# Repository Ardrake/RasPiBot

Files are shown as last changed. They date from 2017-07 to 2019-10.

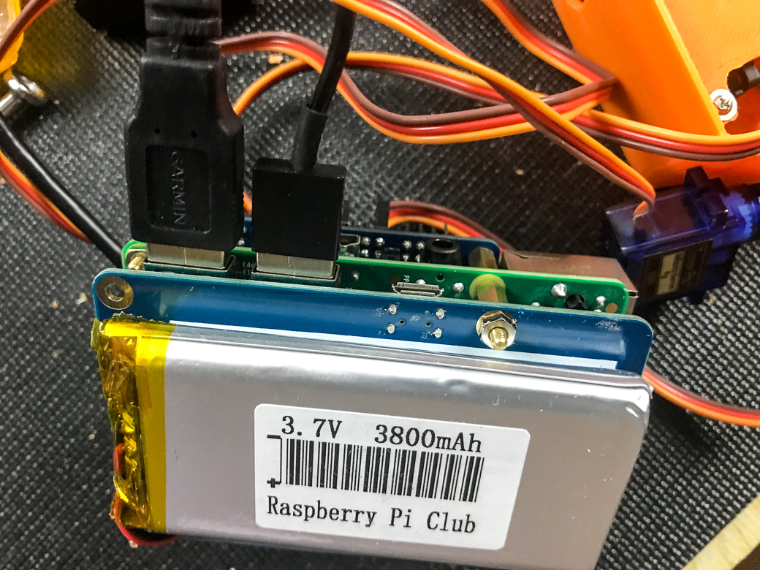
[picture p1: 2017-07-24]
test/Model MG996R/V3/IMG_0332.jpg

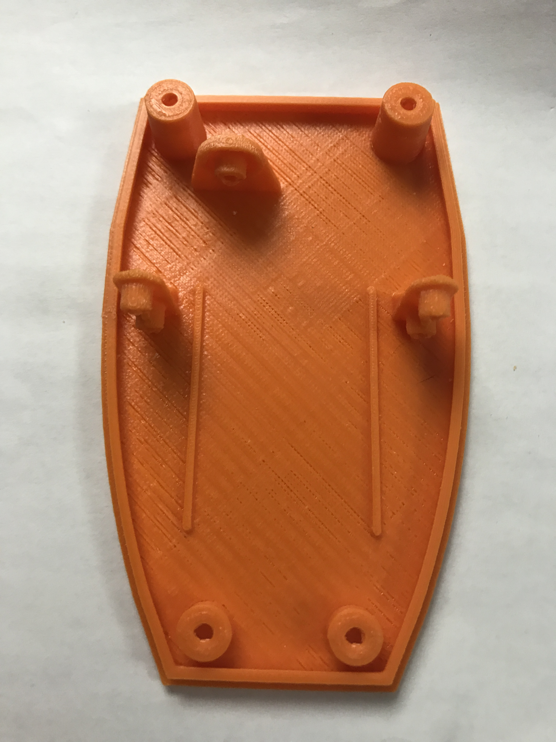
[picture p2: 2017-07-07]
test/Model MG996R/V3/IMG_0251.JPG

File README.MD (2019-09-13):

<p align="center">
    
</p>

<h4 align="center">A remix of the original <a href="http://www.robotshop.com/en/ez-robot-jd-humanoid-robot.html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" target="_blank">JD Robot</a>.</h4>

<p align="center">
<a href="">
    
  </a>
 
     <a href='https://ko-fi.com/A8722AIZ' target='_blank'>Buy Me a Coffee at ko-fi.com
    </a>
     <a href="https://opensource.org/licenses/MIT">
    
  </a>
  <a href="https://github.com/Ardrake">
    
  </a>
</p>

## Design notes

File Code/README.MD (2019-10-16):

## Section code / programation du projet

#### Requis

+ Python 3.6
+ wxPython
+ Adafruit 16-Channel PWM - Servo hat
+ Raspberry Pi B

------

+ Encours
  1. Écran de test pour servos

+ A faire
  1. Gestion et sauvegarde de la calibration des servos
  2. Gestion des mouvements en séquance (macro)
      - enregistrment
      - playback
  3. web cam support
  4. touch screen
  5. Conversion en web app ? / Flask / django

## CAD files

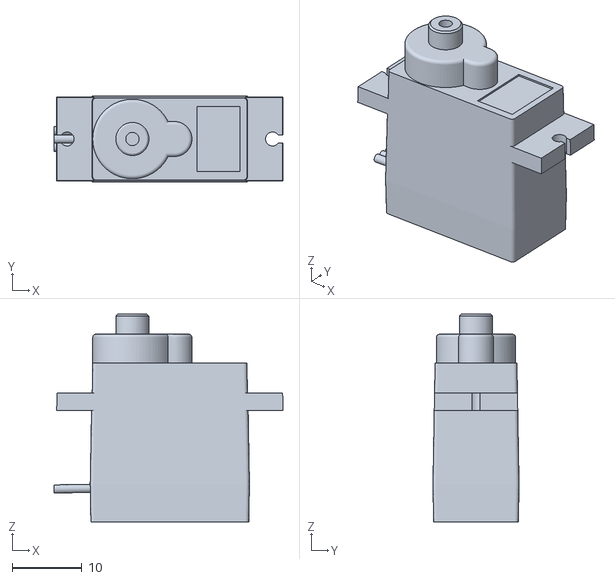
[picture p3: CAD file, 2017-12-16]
3D/Parts/2051_servo_tower-pro-sg90.pk2.stl
32.9 x 12.4 x 29.8

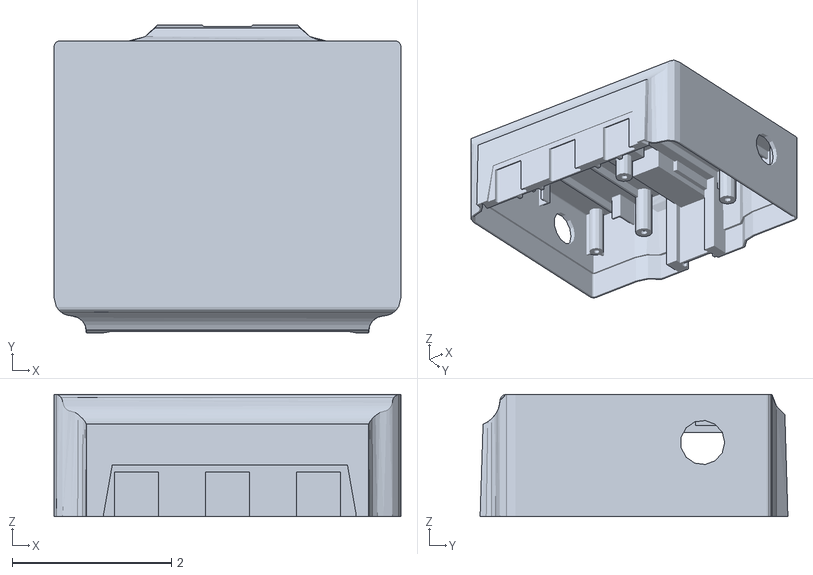
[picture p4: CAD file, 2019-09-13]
stl/P4_A-01_Cooke.stl
4.36 x 3.86 x 1.54

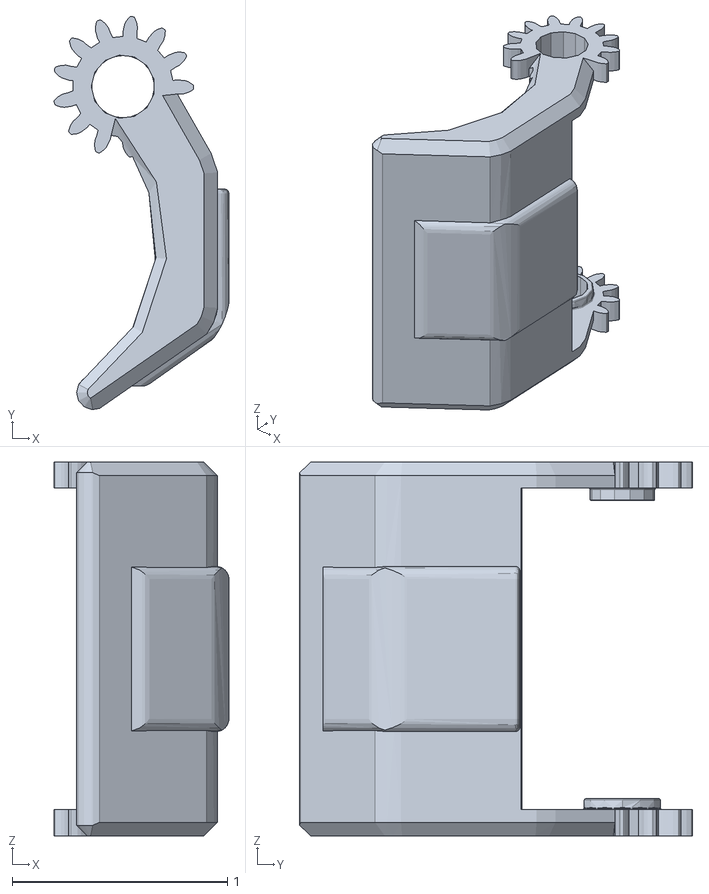
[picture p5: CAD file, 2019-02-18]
stl/P26_A-01_Cooke.stl
0.812 x 1.82 x 1.74

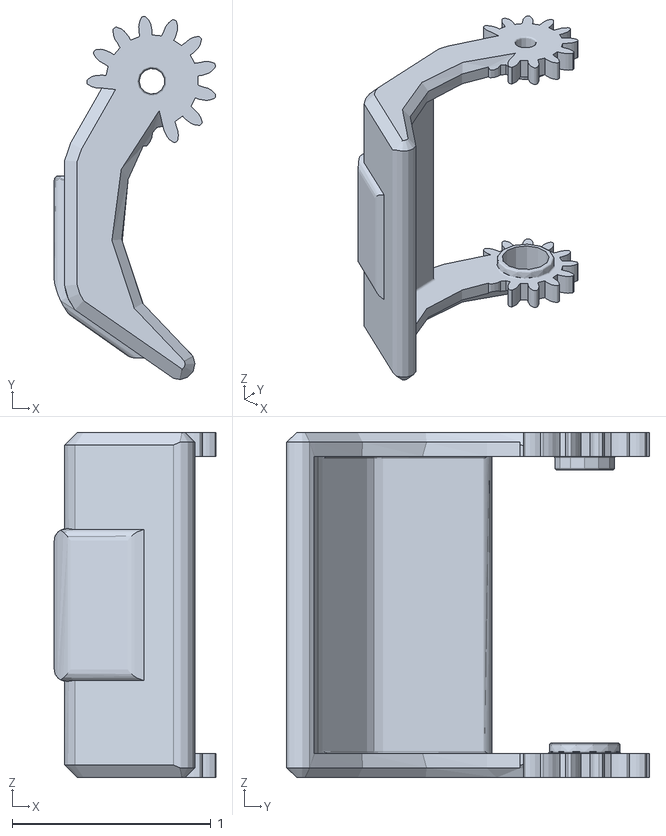
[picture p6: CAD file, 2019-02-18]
stl/P27_A-01_Cooke.stl
0.812 x 1.82 x 1.74

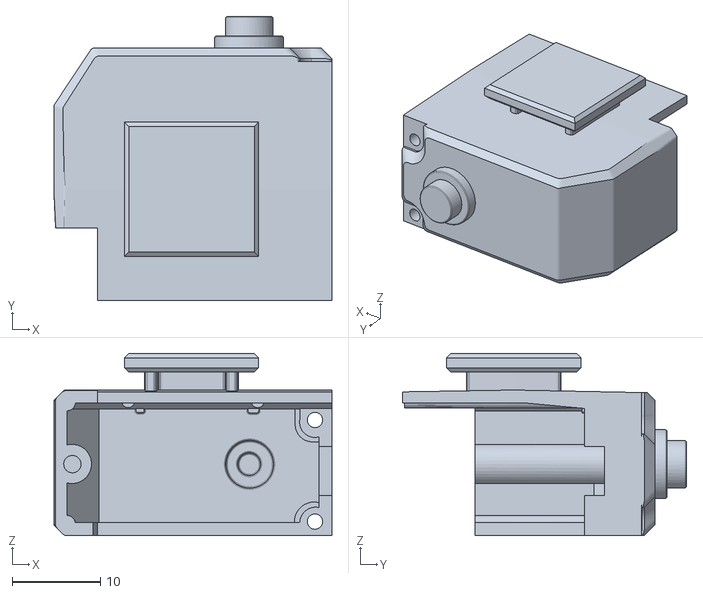
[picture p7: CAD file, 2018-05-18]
stl/P20_A-01_Cooke.stl
31.6 x 32.3 x 20.7

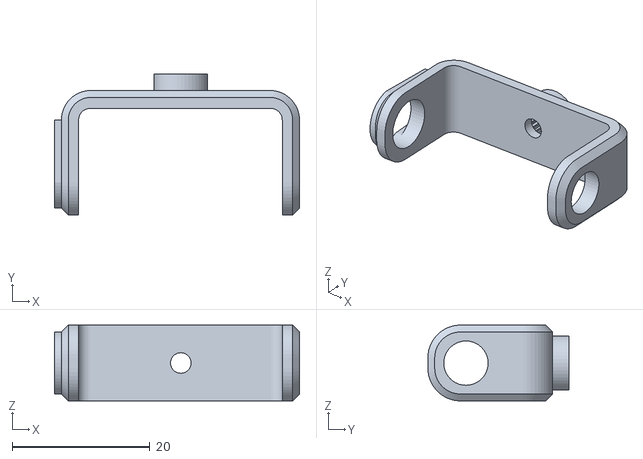
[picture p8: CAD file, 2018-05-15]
stl/P21_A-01_Cooke.stl
35.5 x 20.5 x 11.0

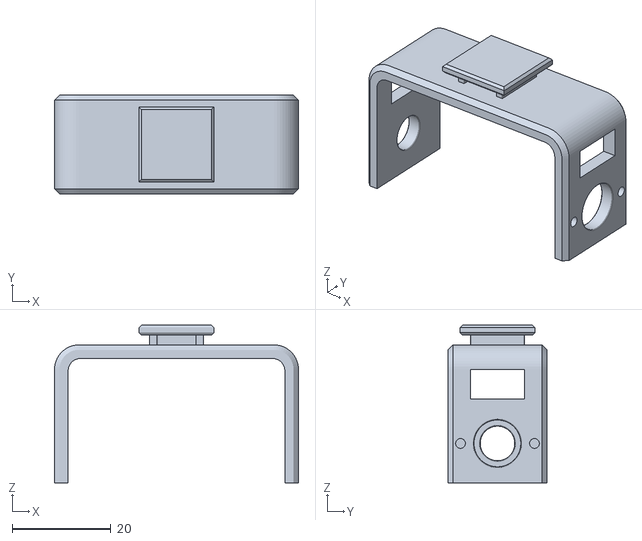
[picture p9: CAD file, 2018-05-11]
stl/P24_A-01_Cooke.stl
49.5 x 20.0 x 32.0

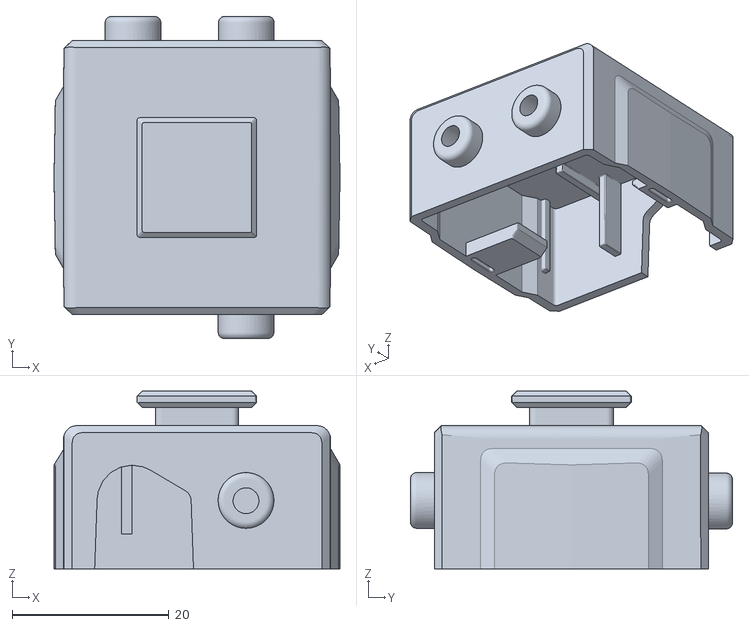
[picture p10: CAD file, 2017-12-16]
stl/P28_A-01_Cooke.stl
36.5 x 41.1 x 22.7

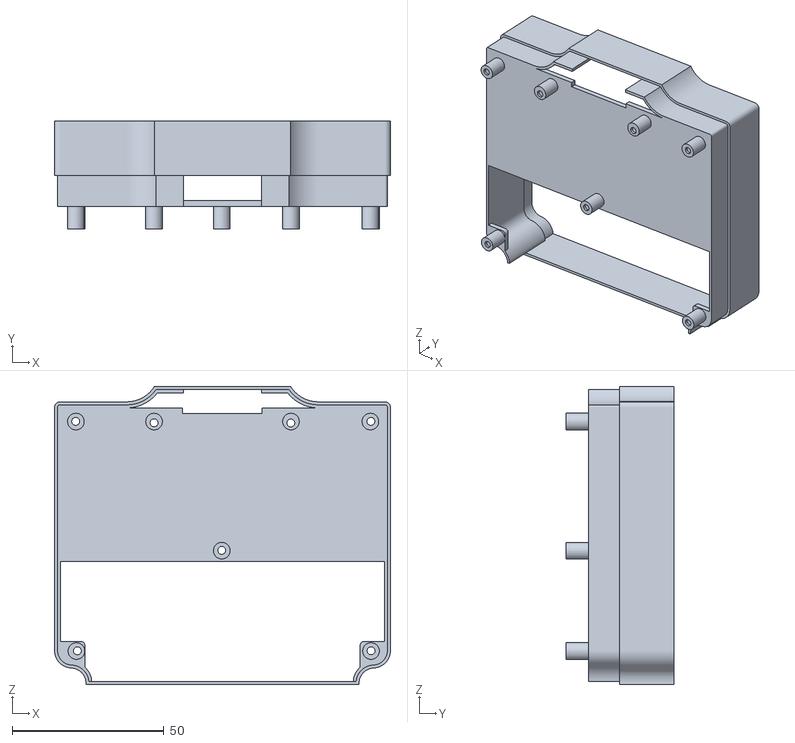
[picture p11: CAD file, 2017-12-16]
stl/Pi_BackPack.stl
110.6 x 35.5 x 98.1

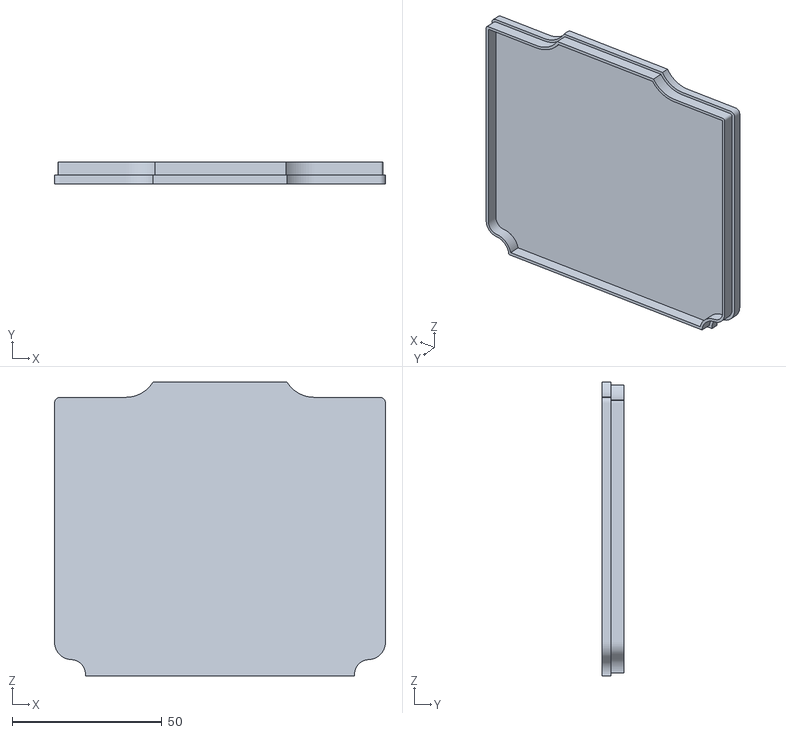
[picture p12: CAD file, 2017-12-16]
stl/BackCover.stl
110.6 x 7.34 x 98.1

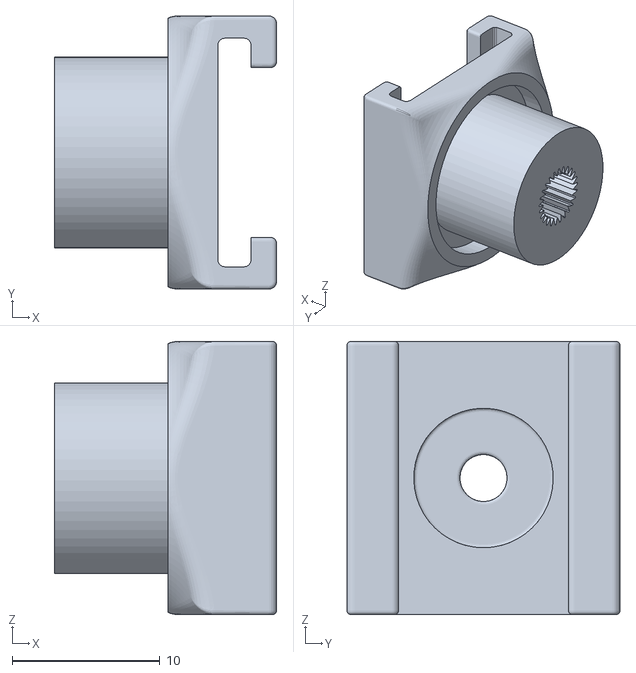
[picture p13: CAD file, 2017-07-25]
stl/P6_A-01_Cooke.stl
15.1 x 18.5 x 18.5

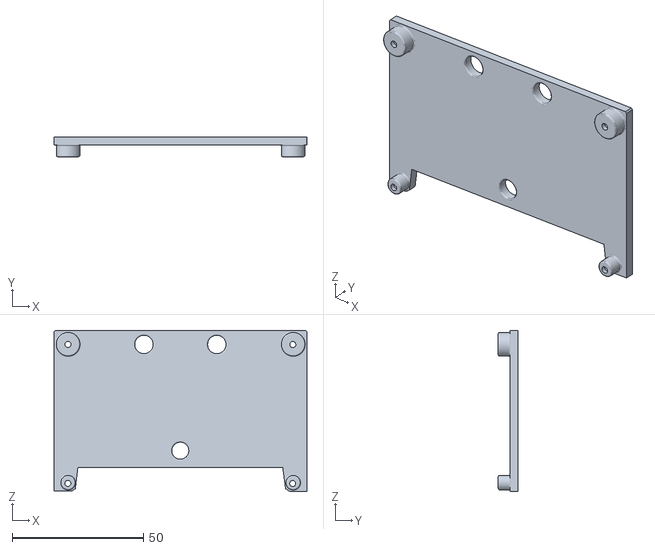
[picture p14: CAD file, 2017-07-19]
stl/P5_A-01_Cooke.stl
96.5 x 7.45 x 61.5

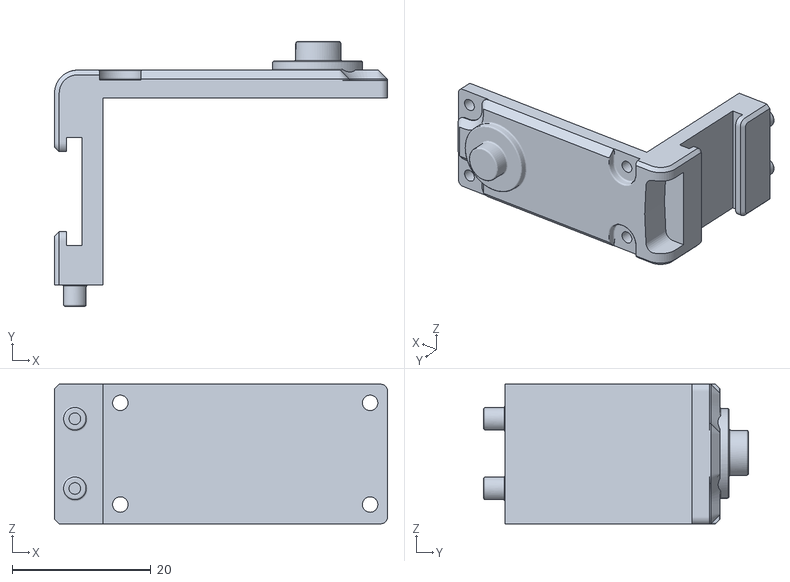
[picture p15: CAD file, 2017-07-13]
stl/P23_A-01_MG996R.stl
48.0 x 38.2 x 20.1

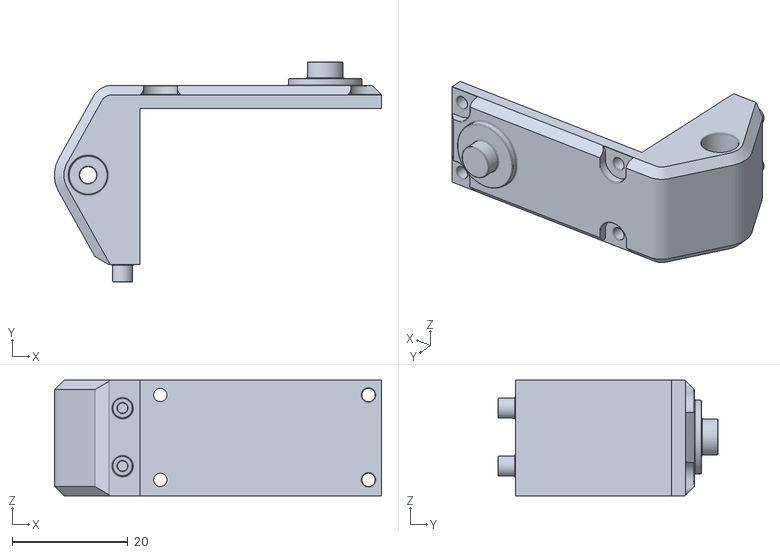
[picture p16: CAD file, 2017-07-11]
stl/P43_A-01_Cooke.stl
56.6 x 38.1 x 20.0

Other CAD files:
stl/P11_A-01_Cooke.stl
stl/P9_A-01_Cooke.stl
stl/P7_A-01_Cooke.stl
stl/P8_A-01_Cooke.stl
stl/P10_A-01_Cooke.stl
stl/P20_A-01.STL
stl/P21_A-01.STL
stl/P24_A-01_MG996R.stl
stl/P2_A-01.STL
stl/P3_A-01.STL
stl/P43_A-01.STL
stl/P5_A-01.STL

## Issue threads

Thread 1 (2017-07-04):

P-23

Ardrake, 2017-07-04:
P-23 needs to be ajusted for 996R servos

Ardrake, 2017-07-04:
Made modifications, will print and test part shortly

Ardrake, 2017-07-06:
Part modified to fit with MG996R motor, and test printed
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

Closed 2017-07-06.

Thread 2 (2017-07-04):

Raspberry PI - Touche screen chest plate

Ardrake, 2017-07-04:
Re-design chest part to include a Raspberry pi touch screen

Ardrake, 2017-07-19:
Augmenté la dimension en X, Y et z du chest pour fitté un Pi, ajusté les support pour les moteur MG996R, le back plate et back pack sont a suivre

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

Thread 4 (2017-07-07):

P-20 - screw tower

Ardrake, 2017-07-07:
Increase screw tower size, broke when screwed to bottom

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

Ardrake, 2017-07-08:
Piece modifié, besoin de re-imprimé pour validé modification

Ardrake, 2017-07-11:
Pièce imprimé et validé

Closed 2017-07-11.

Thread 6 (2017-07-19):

Battery / énergie portable

Ardrake, 2017-07-19:
quel sont les besoins et les options de batteries a utiliser pour le projet, faut t'il prévoir de l'espace dans le chest / backplate pour ceux si ??

SLAY666, 2017-07-19:
Je suis rendu là! Je connais vraiment pas ça! Le JD original a une belle
batterie qui fitte parfaitement par dessus les senseurs dans le Chest.
Cependant, je ne sais pas si elle peut gérer le PI et le hat.

Connais-tu ça un peu? Est-ce qu'une même batterie peut gérer 2 devices?

Le 19 juil. 2017 08:20, "André Cooke" <notifications@github.com> a écrit :

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

Ardrake, 2017-07-19:
Adafruit recommend, ceci pour le servo hat
4xAA Battery Holder - 6v with Alkaline cells.
4.8v with NiMH rechargeable cells, portable!
4.8 or 6v Rechargeable RC battery packs from a hobby store.

Ardrake, 2017-07-19:
ceci semble intéressant, 2 output de 5V, un pour le Pi et un pour le servo hat

https://www.adafruit.com/product/1566

Ardrake, 2017-07-19:
Option chinoise moins cher

http://www.gearbest.com/raspberry-pi/pp_603488.html#.WW9gP5KOxDY.link

SLAY666, 2017-07-19:
Oh que j'aime l'option chinoise, tu penses ça entre dans le Chest ou que ça
pourrait sarrimer avec le Chest d'une quelconque façon?

Le 19 juil. 2017 09:39, "André Cooke" <notifications@github.com> a écrit :

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

Ardrake, 2017-07-19:
http://amzn.to/2tf75Aa

connecteur USB a DC jack, mais un peut long, et après avoir regarder ça un peut splicé un cable usb direct

http://www.instructables.com/id/Provide-Power-With-an-Old-USB-Cord/

Ardrake, 2017-07-19:
http://amzn.to/2tGsP7l

Bon avec Amazon prime, je reçoit ça dans 2 jours, je vais branché en fds pour voir ça donne quoi! et si ca fonctionne, je vais modifié le chest pour lui trouvé un place, et avoir un accès pour le branché le fils du chargeur

SLAY666, 2017-07-19:
Wow, tu es en feu!!

Le 19 juillet 2017 à 10:56, André Cooke <notifications@github.com> a écrit :

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

Ardrake, 2017-07-21:
ca semble avoir pas mal d'allure la batterie, reste a voir comment inséré ca pour que ca prend le moins d'espace, ca fait 1 3/4 de de pouce d'épais quand on stack le tous

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

SLAY666, 2017-07-21:
Wow est cool ta batterie, je pensais qu'elle serait plus grosse. Sur JD,
ils placent la batterie sous les moteurs. Voir la photo, ça enlèverait de
l'épaisseur.

Es-tu en vacances pour 3 semaines?

Le 20 juil. 2017 22:59, "André Cooke" <notifications@github.com> a écrit :

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

Ardrake, 2017-07-21:
oui, asser grosse, les dimension hors tous sont de 8.5 cm X 5.5 cm x 2 cm, sous les moteurs ces un bonne idée, j'avais commencer a dégagé la zone et voir comment ca pourrait si logé.

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

le carré jaune étant l'espace requise pour la batterie, c'étais avant que je la reçoive par contre, la je vais peaufiné ça un peut.

Non malheureusement les vacances l'été c'est pas évident pour moi, c'est notre saison forte.

Dans mon domaine, j'ai une semaine seulement l'été, que je prend en septembre cette année, mais je me reprend cette hivers avec 4 semaine de congé au fêtes

Ardrake, 2017-08-18:
Battery testé et fonctionnelle, pour le build du robot, reste a validés les 3D et positionnement.

Je ferme cette issue

Closed 2017-08-18.

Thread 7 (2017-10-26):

Moteur SG90

Ardrake, 2017-10-26:
le moteur SG90 est plus petit que le moteur d'origine, modification des pièce requise

Ardrake, 2017-10-26:
J'ai modifé la piece P-28-A-01, elle doit etre imprimé et testé

SLAY666, 2017-10-26:
Merci je vais tester ça!!

2017-10-26 14:57 GMT-04:00 André Cooke <notifications@github.com>:

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

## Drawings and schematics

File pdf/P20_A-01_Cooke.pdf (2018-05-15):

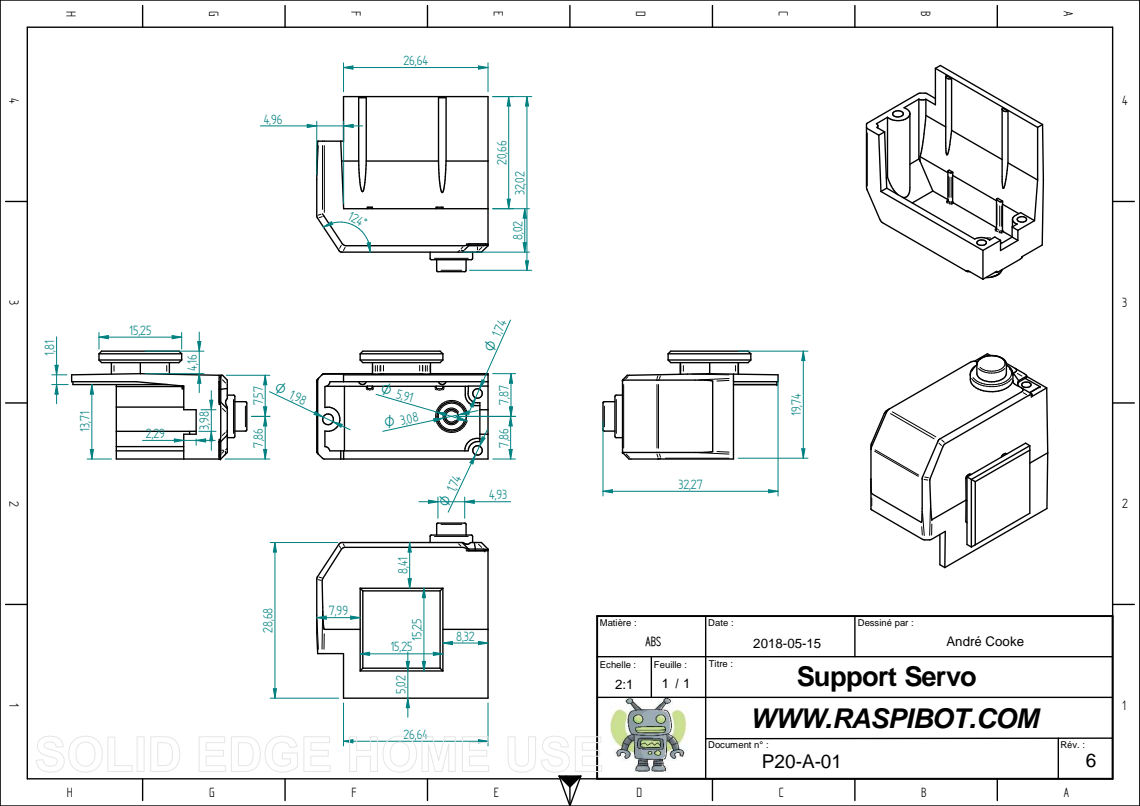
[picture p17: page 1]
HGFEDCB

Matière : ABS | Date : 2018-05-15 | Dessiné par : André Cooke

Echelle : 2:1 | Feuille : 1 1/ | Titre : Support Servo

WWW.RASPIBOT.COM

Document n° : P20-A-01 | Rév. : 6

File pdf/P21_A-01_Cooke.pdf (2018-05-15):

4

29,53

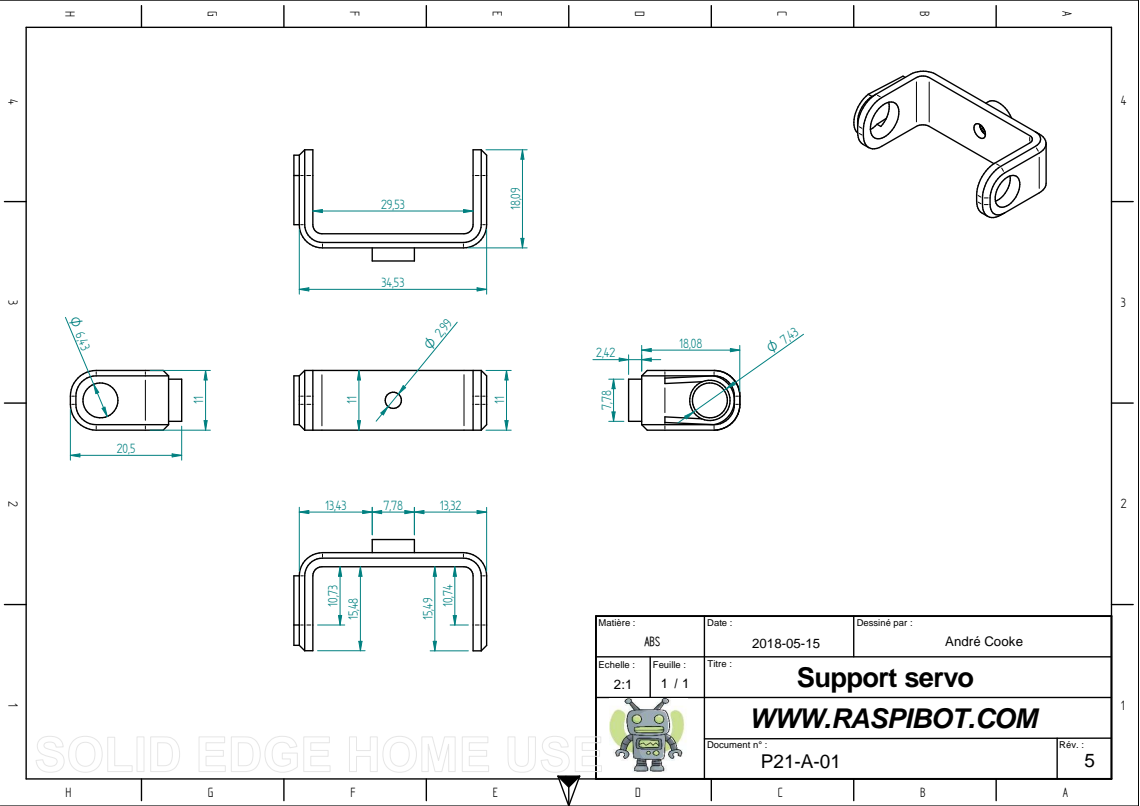
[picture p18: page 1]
HGFEDCB

Matière : ABS | Date : 2018-05-15 | Dessiné par : André Cooke

Echelle : 2:1 | Feuille : 1 1/ | Titre : Support servo

WWW.RASPIBOT.COM

Document n° : P21-A-01 | Rév. : 5

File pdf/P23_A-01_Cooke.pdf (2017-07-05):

4

40

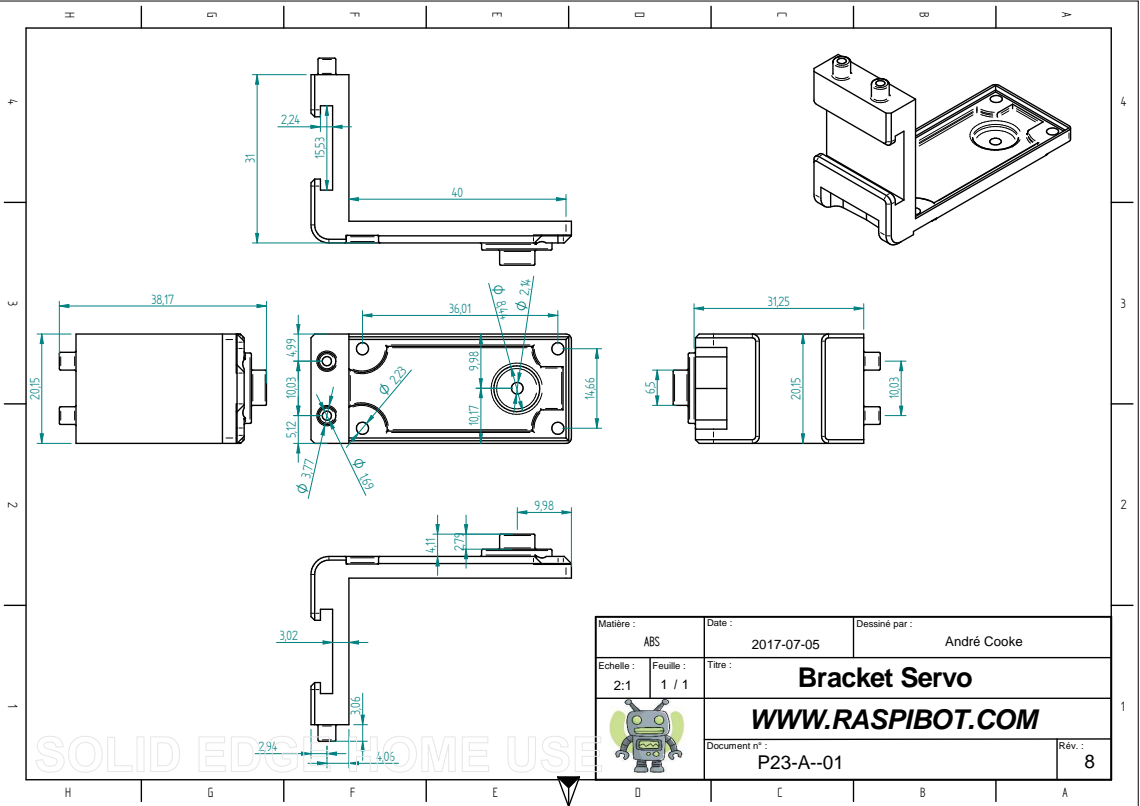
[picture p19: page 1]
HGFEDCB

Matière : ABS | Date : 2017-07-05 | Dessiné par : André Cooke

Echelle : 2:1 | Feuille : 1 1/ | Titre : Bracket Servo

WWW.RASPIBOT.COM

Document n° : P23-A--01 | Rév. : 8

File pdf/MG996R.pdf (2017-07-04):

4

5,9

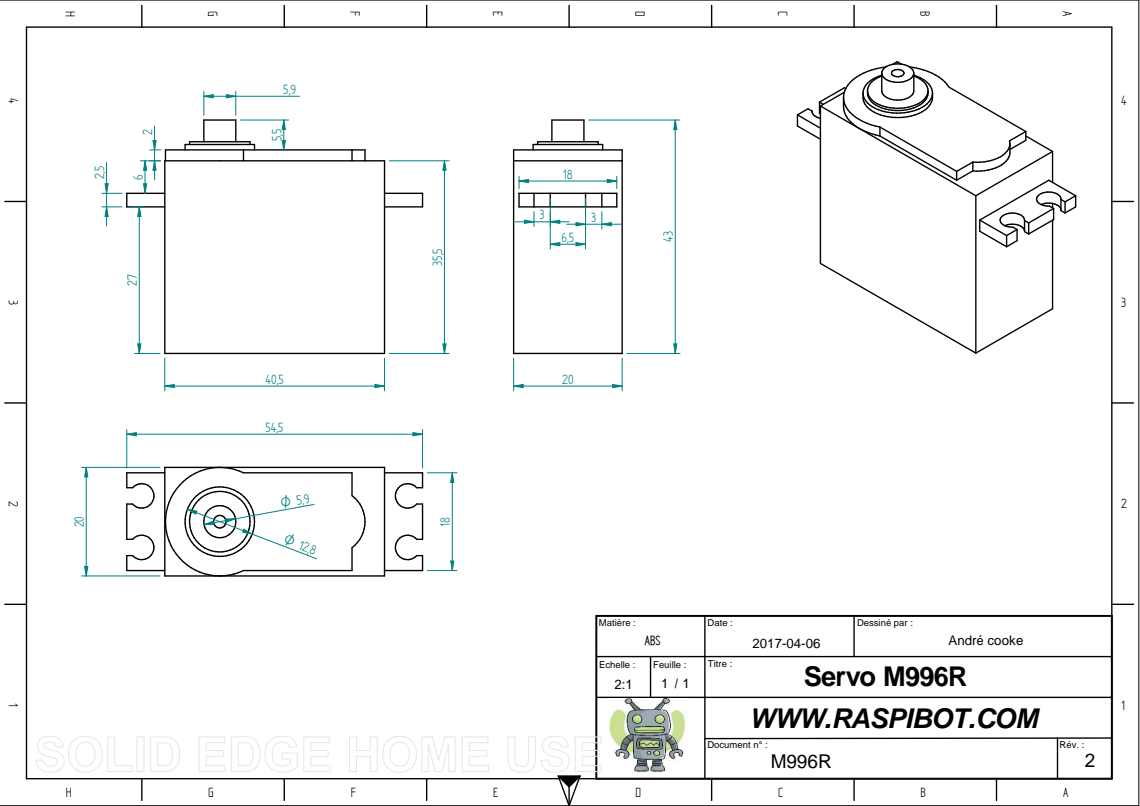
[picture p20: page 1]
HGFEDCB

Matière : ABS | Date : 2017-04-06 | Dessiné par : André cooke

Echelle : 2:1 | Feuille : 1 1/ | Titre : Servo M996R

WWW.RASPIBOT.COM

Document n° : M996R | Rév. : 2

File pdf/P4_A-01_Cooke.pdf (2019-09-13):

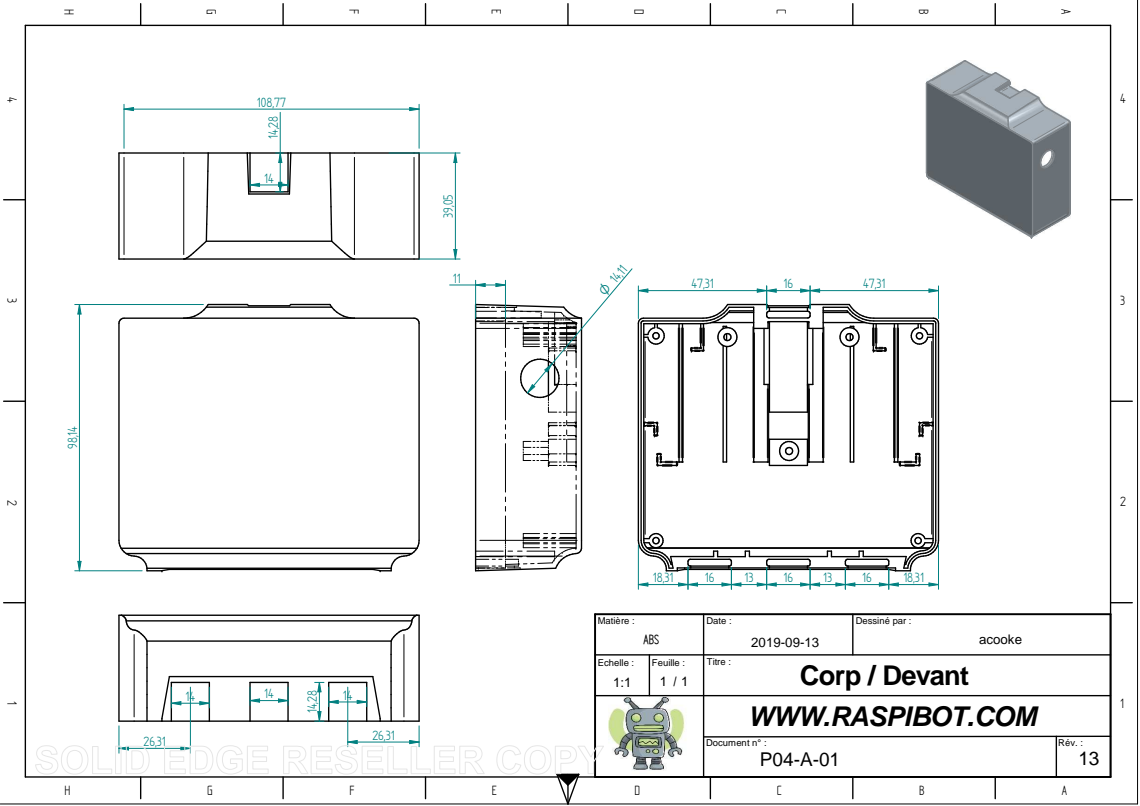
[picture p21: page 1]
HGFEDCB

Matière : ABS | Date : 2019-09-13 | Dessiné par : acooke

Echelle : 1:1 | Feuille : 1 1/ | Titre : Corp / Devant

WWW.RASPIBOT.COM

Document n° : P04-A-01 | Rév. : 13

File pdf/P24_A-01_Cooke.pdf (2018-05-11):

4

25,23

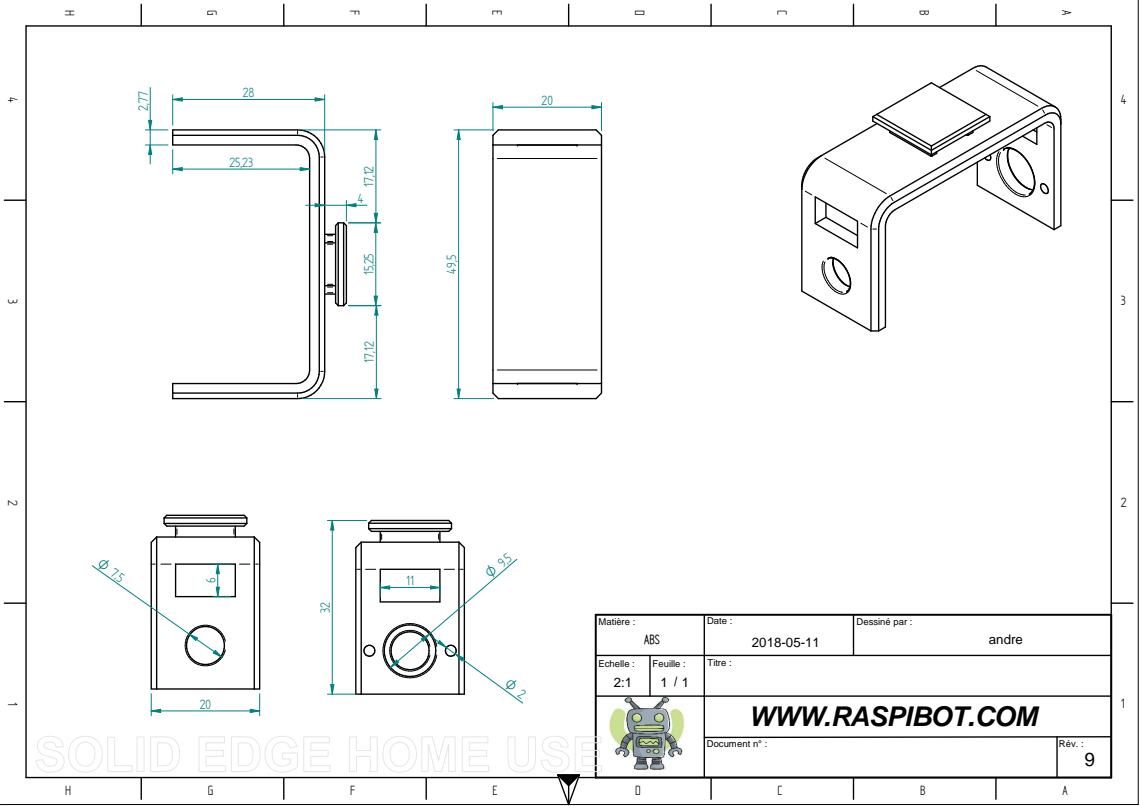
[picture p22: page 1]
HGFEDCB

Matière : ABS | Date : 2018-05-11 | Dessiné par : andre

Echelle : 2:1 | Feuille : 1 1/ | Titre :

WWW.RASPIBOT.COM

Document n° : | Rév. : 9

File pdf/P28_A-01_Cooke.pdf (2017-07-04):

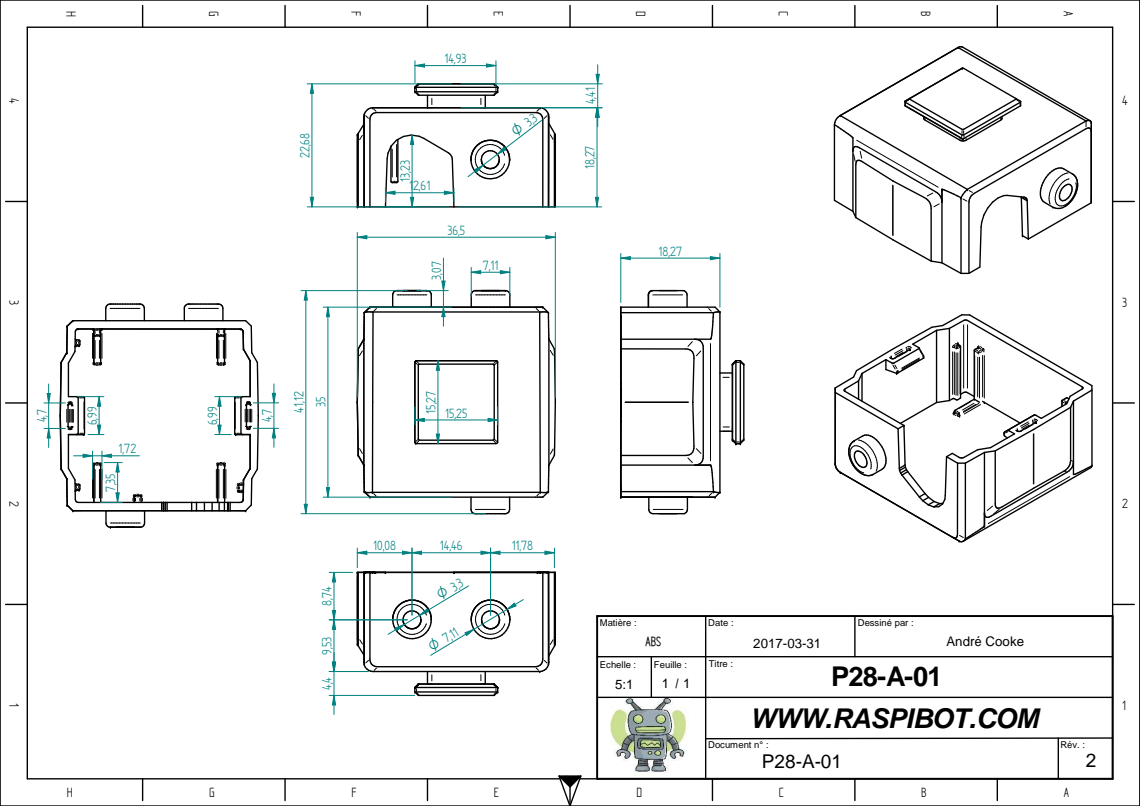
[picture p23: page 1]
HGFEDCB

Matière : ABS | Date : 2017-03-31 | Dessiné par : André Cooke

Echelle : 5:1 | Feuille : 1 1/ | Titre : P28-A-01

WWW.RASPIBOT.COM

Document n° : P28-A-01 | Rév. : 2

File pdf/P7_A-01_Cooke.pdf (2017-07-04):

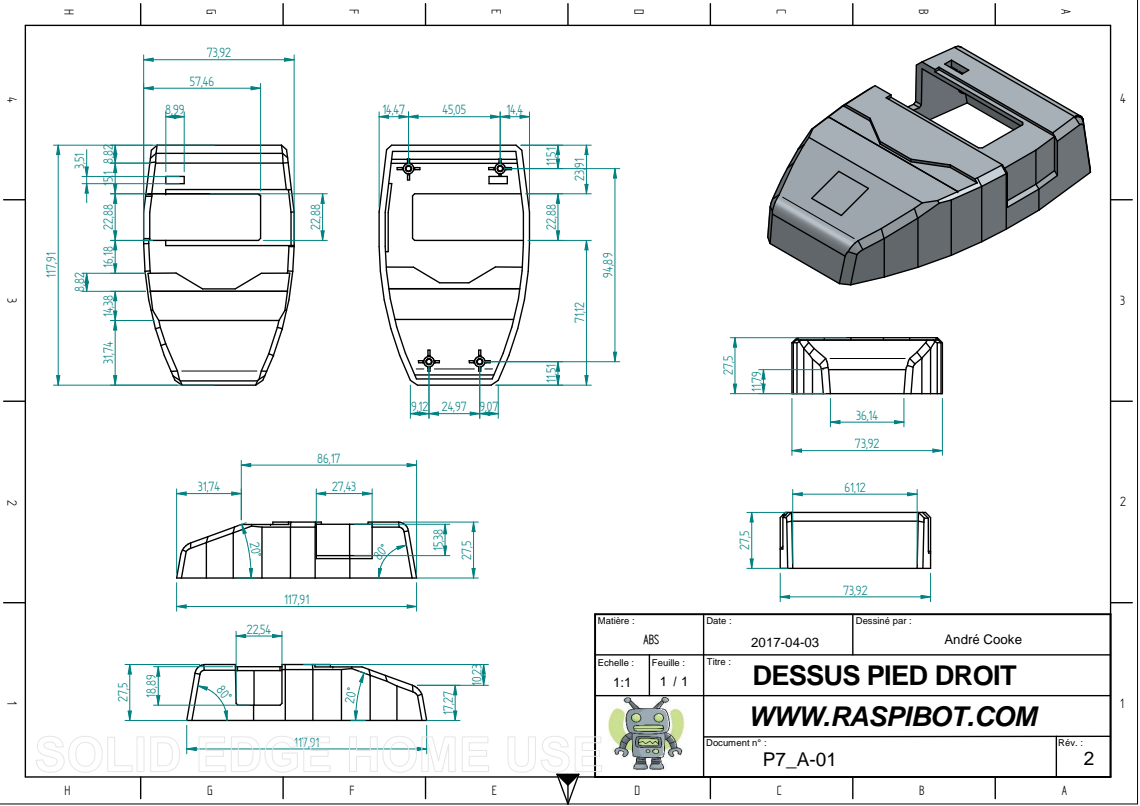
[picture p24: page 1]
HGFEDCB

Matière : ABS | Date : 2017-04-03 | Dessiné par : André Cooke

Echelle : 1:1 | Feuille : 1 1/ | Titre : DESSUS PIED DROIT

WWW.RASPIBOT.COM

Document n° : P7_A-01 | Rév. : 2

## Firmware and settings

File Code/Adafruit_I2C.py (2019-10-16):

#!/usr/bin/python
import re
import smbus

# ===========================================================================
# Adafruit_I2C Class
# ===========================================================================

class Adafruit_I2C(object):

  @staticmethod
  def getPiRevision():
    "Gets the version number of the Raspberry Pi board"
    # Revision list available at: http://elinux.org/RPi_HardwareHistory#Board_Revision_History
    try:
      with open('/proc/cpuinfo', 'r') as infile:
        for line in infile:
          # Match a line of the form "Revision : 0002" while ignoring extra
          # info in front of the revsion (like 1000 when the Pi was over-volted).
          match = re.match('Revision\s+:\s+.*(\w{4})$', line)
          if match and match.group(1) in ['0000', '0002', '0003']:
            # Return revision 1 if revision ends with 0000, 0002 or 0003.
            return 1
          elif match:
            # Assume revision 2 if revision ends with any other 4 chars.
            return 2
        # Couldn't find the revision, assume revision 0 like older code for compatibility.
        return 0
    except:
      return 0

  @staticmethod
  def getPiI2CBusNumber():
    # Gets the I2C bus number /dev/i2c#
    return 1 if Adafruit_I2C.getPiRevision() > 1 else 0

  def __init__(self, address, busnum=-1, debug=False):
    self.address = address
    # By default, the correct I2C bus is auto-detected using /proc/cpuinfo
    # Alternatively, you can hard-code the bus version below:
    # self.bus = smbus.SMBus(0); # Force I2C0 (early 256MB Pi's)
    # self.bus = smbus.SMBus(1); # Force I2C1 (512MB Pi's)
    self.bus = smbus.SMBus(busnum if busnum >= 0 else Adafruit_I2C.getPiI2CBusNumber())
    self.debug = debug

  def reverseByteOrder(self, data):
    "Reverses the byte order of an int (16-bit) or long (32-bit) value"
    # Courtesy Vishal Sapre
    byteCount = len(hex(data)[2:].replace('L','')[::2])
    val       = 0
    for i in range(byteCount):
      val    = (val << 8) | (data & 0xff)
      data >>= 8
    return val

  def errMsg(self):
    print("Error accessing 0x%02X: Check your I2C address" % self.address)
    return -1

  def write8(self, reg, value):
    "Writes an 8-bit value to the specified register/address"
    try:
      self.bus.write_byte_data(self.address, reg, value)
      if self.debug:
        print("I2C: Wrote 0x%02X to register 0x%02X" % (value, reg))
    except IOError as err:
      return self.errMsg()

  def write16(self, reg, value):
    "Writes a 16-bit value to the specified register/address pair"
    try:
      self.bus.write_word_data(self.address, reg, value)
      if self.debug:
        print ("I2C: Wrote 0x%02X to register pair 0x%02X,0x%02X" %
         (value, reg, reg+1))
    except IOError as err:
      return self.errMsg()

  def writeRaw8(self, value):
    "Writes an 8-bit value on the bus"
    try:
      self.bus.write_byte(self.address, value)
      if self.debug:
        print ("I2C: Wrote 0x%02X" % value)
    except IOError as err:
      return self.errMsg()

  def writeList(self, reg, list):
    "Writes an array of bytes using I2C format"
    try:
      if self.debug:
        print ("I2C: Writing list to register 0x%02X:" % reg)
        print (list)
      self.bus.write_i2c_block_data(self.address, reg, list)
    except IOError as err:
      return self.errMsg()

  def readList(self, reg, length):
    "Read a list of bytes from the I2C device"
    try:
      results = self.bus.read_i2c_block_data(self.address, reg, length)
      if self.debug:
        print ("I2C: Device 0x%02X returned the following from reg 0x%02X" %
         (self.address, reg))
        print (results)
      return results
    except IOError as err:
      return self.errMsg()

  def readU8(self, reg):
    "Read an unsigned byte from the I2C device"
    try:
      result = self.bus.read_byte_data(self.address, reg)
      if self.debug:
        print ("I2C: Device 0x%02X returned 0x%02X from reg 0x%02X" %
         (self.address, result & 0xFF, reg))
      return result
    except IOError as err:
      return self.errMsg()

  def readS8(self, reg):
    "Reads a signed byte from the I2C device"
    try:
      result = self.bus.read_byte_data(self.address, reg)
      if result > 127: result -= 256
      if self.debug:
        print ("I2C: Device 0x%02X returned 0x%02X from reg 0x%02X" %
         (self.address, result & 0xFF, reg))
      return result
    except IOError as err:
      return self.errMsg()

  def readU16(self, reg, little_endian=True):
    "Reads an unsigned 16-bit value from the I2C device"
    try:
      result = self.bus.read_word_data(self.address,reg)
      # Swap bytes if using big endian because read_word_data assumes little
      # endian on ARM (little endian) systems.
      if not little_endian:
        result = ((result << 8) & 0xFF00) + (result >> 8)
      if (self.debug):
        print ("I2C: Device 0x%02X returned 0x%04X from reg 0x%02X" % (self.address, result & 0xFFFF, reg))
      return result
    except IOError as err:
      return self.errMsg()

  def readS16(self, reg, little_endian=True):
    "Reads a signed 16-bit value from the I2C device"
    try:
      result = self.readU16(reg,little_endian)
      if result > 32767: result -= 65536
      return result
    except IOError as err:
      return self.errMsg()

if __name__ == '__main__':
  try:
    bus = Adafruit_I2C(address=0)
    print ("Default I2C bus is accessible")
  except:
    print ("Error accessing default I2C bus")

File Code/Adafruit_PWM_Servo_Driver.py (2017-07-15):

#!/usr/bin/python

import time
import math
from Adafruit_I2C import Adafruit_I2C


# ============================================================================
# Adafruit PCA9685 16-Channel PWM Servo Driver
# ============================================================================

class PWM:
    # Registers/etc.
    __MODE1 = 0x00
    __MODE2 = 0x01
    __SUBADR1 = 0x02
    __SUBADR2 = 0x03
    __SUBADR3 = 0x04
    __PRESCALE = 0xFE
    __LED0_ON_L = 0x06
    __LED0_ON_H = 0x07
    __LED0_OFF_L = 0x08
    __LED0_OFF_H = 0x09
    __ALL_LED_ON_L = 0xFA
    __ALL_LED_ON_H = 0xFB
    __ALL_LED_OFF_L = 0xFC
    __ALL_LED_OFF_H = 0xFD

    # Bits
    __RESTART = 0x80
    __SLEEP = 0x10
    __ALLCALL = 0x01
    __INVRT = 0x10
    __OUTDRV = 0x04

    general_call_i2c = Adafruit_I2C(0x00)

    @classmethod
    def softwareReset(cls):
        "Sends a software reset (SWRST) command to all the servo drivers on the bus"
        cls.general_call_i2c.writeRaw8(0x06)  # SWRST

    def __init__(self, address=0x40, debug=False):
        self.i2c = Adafruit_I2C(address)
        self.i2c.debug = debug
        self.address = address
        self.debug = debug
        if (self.debug):
            print
            "Reseting PCA9685 MODE1 (without SLEEP) and MODE2"
        self.setAllPWM(0, 0)
        self.i2c.write8(self.__MODE2, self.__OUTDRV)
        self.i2c.write8(self.__MODE1, self.__ALLCALL)
        time.sleep(0.005)  # wait for oscillator

        mode1 = self.i2c.readU8(self.__MODE1)
        mode1 = mode1 & ~self.__SLEEP  # wake up (reset sleep)
        self.i2c.write8(self.__MODE1, mode1)
        time.sleep(0.005)  # wait for oscillator

    def setPWMFreq(self, freq):
        "Sets the PWM frequency"
        prescaleval = 25000000.0  # 25MHz
        prescaleval /= 4096.0  # 12-bit
        prescaleval /= float(freq)
        prescaleval -= 1.0
        if (self.debug):
            print
            "Setting PWM frequency to %d Hz" % freq
            print
            "Estimated pre-scale: %d" % prescaleval
        prescale = math.floor(prescaleval + 0.5)
        if (self.debug):
            print
            "Final pre-scale: %d" % prescale

        oldmode = self.i2c.readU8(self.__MODE1);
        newmode = (oldmode & 0x7F) | 0x10  # sleep
        self.i2c.write8(self.__MODE1, newmode)  # go to sleep
        self.i2c.write8(self.__PRESCALE, int(math.floor(prescale)))
        self.i2c.write8(self.__MODE1, oldmode)
        time.sleep(0.005)
        self.i2c.write8(self.__MODE1, oldmode | 0x80)

    def setPWM(self, channel, on, off):
        "Sets a single PWM channel"
        self.i2c.write8(self.__LED0_ON_L + 4 * channel, on & 0xFF)
        self.i2c.write8(self.__LED0_ON_H + 4 * channel, on >> 8)
        self.i2c.write8(self.__LED0_OFF_L + 4 * channel, off & 0xFF)
        self.i2c.write8(self.__LED0_OFF_H + 4 * channel, off >> 8)

    def setAllPWM(self, on, off):
        "Sets a all PWM channels"
        self.i2c.write8(self.__ALL_LED_ON_L, on & 0xFF)
        self.i2c.write8(self.__ALL_LED_ON_H, on >> 8)
        self.i2c.write8(self.__ALL_LED_OFF_L, off & 0xFF)
        self.i2c.write8(self.__ALL_LED_OFF_H, off >> 8)

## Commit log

2017-07-04 Modfication piece P23, ajustement servos 996R
    [P23_A-01_Cooke.stl]
2017-07-04 Update draft P23 et correction de nom de repertoire
2017-07-05 modif piece P23 et P24
    [P23_A-01_Cooke.stl]
2017-07-06 ajustement piece P23 et P24 suite a print test
    [P23_A-01_MG996R.stl, P24_A-01_Cooke.stl, P24_A-01_MG996R.stl]
2017-07-06 Added images of printed pieces
2017-07-06 Housekeeping removing old files
    [P23_A-01.STL, P24_A-01.STL]
2017-07-07 stl et test print de P-8
    [P10_A-01.STL, P10_A-01_Cooke.stl, P8_A-01.STL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]
2017-07-07 modif de couvercle des patte, grossir collone de vissage - trop fragile
2017-07-08 Modification piece P-09 support de patte pour moteur MG996R
2017-07-11 Modif P7 et P43 pour moteur MG996R
    [P11_A-01.STL, P11_A-01_Cooke.stl, P43_A-01_Cooke.stl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]
2017-07-13 Stl et Print du corp / chest et ajustement mineur sur P23
    [P23_A-01_MG996R.stl, P4_A-01_Cooke.stl]
2017-07-13 test result image assembly both legs
2017-07-13 travail sur interface de test des servos
2017-07-14 make stl print file for gripper base
    [P28_A-01_Cooke.stl, P6_A-01_Cooke.stl]
2017-07-14 rajout de l'affichage des valeur en angle des servos avec la logique pour les modifiés
2017-07-14 import model de RPi3 et début modif du chest
2017-07-15 connected Servo hat to code - debug UI
2017-07-15 rajout du mouvement au servo
2017-07-16 Ajustement de l'ecran et creation de menu
2017-07-18 Modelisation du chest et backpack
    [P28_A-01.STL, P4_A-01.STL, P6_A-01.STL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]
2017-07-18 modif chest, test de concept
2017-07-19 Published stl for chest and shoulder
    [P4_A-01_Cooke.stl, P6_A-01_Cooke.stl]
2017-07-19 Picture of printed chest - front part
2017-07-19 Published Stl of robot
2017-07-19 Servo and battery pack place holder
2017-07-19 Travail sur chest et Pi backpack
    [BackCover.stl, P5_A-01_Cooke.stl, Pi_BackPack.stl]
2017-07-21 travail sur épaule, prob d'impression de la piece
    [P6_A-01_Cooke.stl]
2017-07-24 Rajout d'image du battery pack, et travail sur épaule
    [P6_A-01_Cooke.stl]
2017-07-25 Minor tweaks before test print chest / shoulder
    [P4_A-01_Cooke.stl, P6_A-01_Cooke.stl]
2017-07-26 modif chest
    [P4_A-01_Cooke.stl]
2017-07-26 Travail sur chest, fit pi, servo hat et batterie
2017-07-28 Grossir de nouveau le chest, travail sur piece adjacente
2017-08-18 Published stl for print
    [P4_A-01_Cooke.stl]
2017-09-28 publication des STL pour le chest, backpak et couvercle
    [BackCover.stl, Pi_BackPack.stl]
2017-10-26 modifié le P28 pour supporté les moteur SG90
    [2051_servo_tower-pro-sg90.pk2.stl, P28_A-01_Cooke.stl]
2017-10-26 ajustement levre du dessus piece P28
    [P28_A-01_Cooke.stl]
2017-12-16 Modification de P-24
    [P24_A-01_Cooke.stl]
2018-05-08 Modif trou de vis piece P24
2018-05-08 généré PDF et STL piece P24
    [P24_A-01_Cooke.stl]
2018-05-08 augmenté dimension trou pour bracket moteur de 7.5 a 8.5 mm sur P24
    [P24_A-01_Cooke.stl]
2018-05-10 agrandi le trou pour la bracket du moteur de 1mm
    [P24_A-01_Cooke.stl]
2018-05-11 Augmenté trou de vis P24
    [P24_A-01_Cooke.stl]
2018-05-14 Modif piece P20 et P21
    [P20_A-01_Cooke.stl, P21_A-01_Cooke.stl]
2018-05-15 Modif piece ajustement mineur
    [P20_A-01_Cooke.stl, P21_A-01_Cooke.stl]
2018-05-18 modif piece P20
    [P20_A-01_Cooke.stl]
2019-01-23 Modif Piece P-04
    [P4_A-01_Cooke.stl]
2019-01-23 Modif slot pour patte et espace moteur pour epaule
    [P4_A-01_Cooke.stl]
2019-01-29 Modif chest piece
    [P4_A-01_Cooke.stl]
2019-02-18 Modif chest et pince
    [P26_A-01.STL, P26_A-01_Cooke.stl, P27_A-01.STL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]
2019-09-13 Modification du corp - retrait de 2 mm sur centre chaque coter pour faire plus de place au moteur des epaules
    [P4_A-01_Cooke.stl]
2019-10-21 Setup two tables, Robots and servos
2020-11-13 Loading Robot file with Servo list

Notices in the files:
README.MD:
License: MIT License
